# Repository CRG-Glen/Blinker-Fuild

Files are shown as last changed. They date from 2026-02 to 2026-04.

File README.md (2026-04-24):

# BLINKER FLUID

A completely pointless project.  

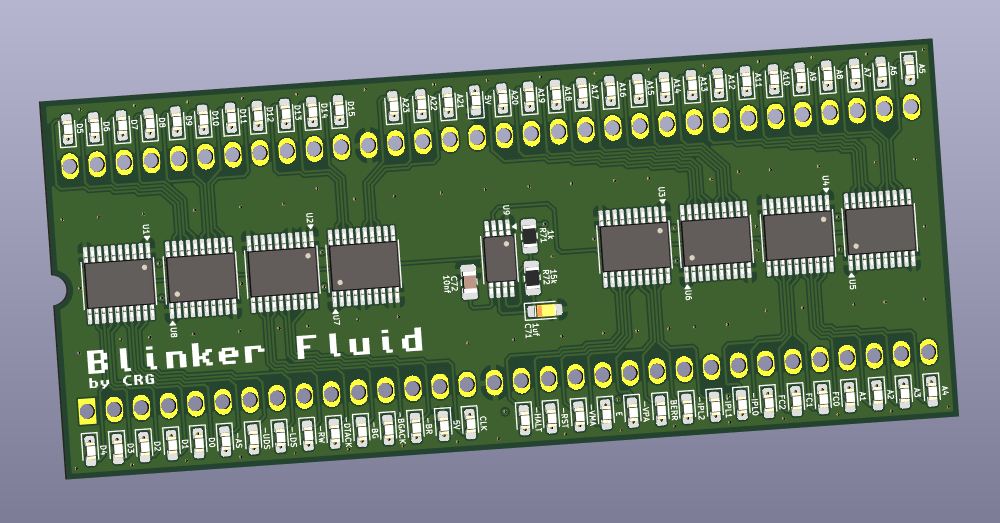
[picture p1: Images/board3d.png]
PCB


## What's this?  

Intended to sit inline with your 68000 CPU with LEDs on each signal that will light when that signal becomes active. 

It's just for fun and should not to be used for any diagnostic purposes, this isn't a logic probe!

There are 8nr 74HCT574s which are sampling each pin on the rising edge of a clock generated by a 555 timer.  
The 555 is running at a rate of approximately 50hz so will miss a lot of activity on the 68k.  There just
isn't enough room to do this with any accuracy but remember this is for fun only.  

You can adjust R71 and R72 to change the speed of the 555. 

## Assembly

Within the JLCPCB folder you will find Gerbers along with a BOM and CPL files suited to LCSC components.

The board can be produced with the HASL finish, no need to pay for EINT on this one but its mostly 0603 so 
get JLC (or equal) to do all SMD work.

Please note the BOM as included takes for RED LEDs for everything.  Feel free to change colours but remember 
you also need to adjust the resistor directly below each LED on the bottom side to suit your LEDs!

To keep the board tidy, there are no LED or Resistor designations on the PCB.  Just remember its all LEDs 
on the top side and all RESISTORs on the bottom side.  

## Bill of Materials

| Designation | Value | Type |
| --- | --- | --- |
| U1 - U8 | 74HCT574 | TSSOP20 |
| U9 | NE555 | TSSOP8 |
| LEDs | pick a colour | 0603 |
| Resistors | to suit your LED | 0603 |
| R71 | 1k ohm 1% | 0805 |
| R72 | 15kohm 1% | 0805 |
| C71 | 1uF | 0805 Tantalum |
| C72 | 10nF |0805 ceramic |
| C1-C8 + C73 | 0.1uF | 0603 ceramic |
| PINS | 0.5mm x 2.54mm x 9.7mm | individual machine pins |

## License

CERN Open Hardware Licence v2

Do with as you like just don't blame me if your computer, console or whatever else you install this in
goes up in smoke!

## Credits

PCB by CRG(Glen)

Artwork by Brick Studios

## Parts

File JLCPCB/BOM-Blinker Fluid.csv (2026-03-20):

Comment | Designator | Footprint | LCSC | Quantity
0.1uf | C1,C2,C3,C4,C5,C6,C7,C73,C8 | C_0603_1608Metric_Pad1.08x0.95mm_HandSolder | C14663 | 9
10nf | C72 | C_0805_2012Metric_Pad1.18x1.45mm_HandSolder | C1710 | 1
15k | R72 | R_0805_2012Metric_Pad1.20x1.40mm_HandSolder | C17475 | 1
1k | R71 | R_0805_2012Metric_Pad1.20x1.40mm_HandSolder | C17513 | 1
1uf | C71 | CP_EIA-2012-12_Kemet-R_Pad1.30x1.05mm_HandSolder | C7174 | 1
470 | R1,R10,R11,R12,R13,R14,R15,R17,R18,R19,R2,R20,R21,R22,R23,R24,R25,R26,R27,R28,R29,R3,R30,R31,R32,R33,R34,R35,R36,R37,R38,R39,R4,R40,R41,R42,R43,R44,R45,R46,R47,R48,R49,R5,R50,R51,R52,R53,R54,R55,R56,R57,R58,R59,R6,R60,R61,R62,R63,R7,R8,R9 | R_0603_1608Metric_Pad0.98x0.95mm_HandSolder | C23179 | 62
74HCT574 | U1,U2,U3,U4,U5,U6,U7,U8 | TSSOP-20_4.4x6.5mm_P0.65mm | C2677898 | 8
NE555 | U9 | TSSOP-8_4.4x3mm_P0.65mm | C105643 | 1
RED | D1,D10,D11,D12,D13,D14,D15,D17,D18,D19,D2,D20,D21,D22,D23,D24,D25,D26,D27,D28,D29,D3,D30,D31,D32,D33,D34,D35,D36,D37,D38,D39,D4,D40,D41,D42,D43,D44,D45,D46,D47,D48,D49,D5,D50,D51,D52,D53,D54,D55,D56,D57,D58,D59,D6,D60,D61,D62,D63,D7,D8,D9 | LED_0603_1608Metric_Pad1.05x0.95mm_HandSolder | C2286 | 62
Conn_02x32_Counter_Clockwise | J1 | DIP-64_W22.86mm_LongPads |  | 1

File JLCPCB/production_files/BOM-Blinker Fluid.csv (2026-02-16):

Comment | Designator | Footprint | LCSC | Quantity
0.1uf | C1,C2,C3,C4,C5,C6,C7,C73,C8 | C_0402_1005Metric_Pad0.74x0.62mm_HandSolder | C141382 | 9
10nf | C72 | C_0402_1005Metric_Pad0.74x0.62mm_HandSolder | C15195 | 1
1k | R71 | R_0402_1005Metric_Pad0.72x0.64mm_HandSolder | C11702 | 1
1uf | C71 | CP_EIA-2012-12_Kemet-R_Pad1.30x1.05mm_HandSolder | C1953183 | 1
330 | R1,R2,R3,R4,R5,R53,R54,R55,R56,R57,R58,R59,R60,R61,R62,R63 | R_0402_1005Metric_Pad0.72x0.64mm_HandSolder | C25104 | 16
470 | R28,R29,R30,R31,R32,R33,R34,R35,R36,R37,R38,R39,R40,R41,R42,R43,R44,R45,R46,R47,R48,R50,R51,R52 | R_0402_1005Metric_Pad0.72x0.64mm_HandSolder | C25117 | 24
47k | R72 | R_0402_1005Metric_Pad0.72x0.64mm_HandSolder | C25792 | 1
680 | R10,R11,R12,R13,R14,R15,R17,R18,R19,R20,R21,R22,R23,R24,R25,R26,R27,R49,R6,R7,R8,R9 | R_0402_1005Metric_Pad0.72x0.64mm_HandSolder | C25130 | 22
74HCT574 | U1,U2,U3,U4,U5,U6,U7,U8 | TSSOP-20_4.4x6.5mm_P0.65mm | C2677898 | 8
BLUE | D10,D11,D12,D13,D15,D17,D18,D19,D20,D21,D22,D23,D24,D25,D26,D27,D28,D6,D7,D8,D9 | LED_0402_1005Metric_Pad0.77x0.64mm_HandSolder | C131223 | 21
Conn_02x32_Counter_Clockwise | J1 | DIP-64_W22.86mm_LongPads | C130723 | 1
GREEN | D29,D30,D31,D32,D33,D34,D35,D36,D37,D38,D39,D40,D41,D42,D43,D44,D45,D46,D47,D48,D50,D51,D52 | LED_0402_1005Metric_Pad0.77x0.64mm_HandSolder | C74338 | 23
NE555 | U9 | TSSOP-8_4.4x3mm_P0.65mm | C105643 | 1
RED | D1,D2,D3,D4,D5,D53,D54,D55,D56,D57,D58,D59,D60,D61,D62,D63 | LED_0402_1005Metric_Pad0.77x0.64mm_HandSolder | C71911 | 16
WHITE | D14,D49 | LED_0402_1005Metric_Pad0.77x0.64mm_HandSolder | C74340 | 2

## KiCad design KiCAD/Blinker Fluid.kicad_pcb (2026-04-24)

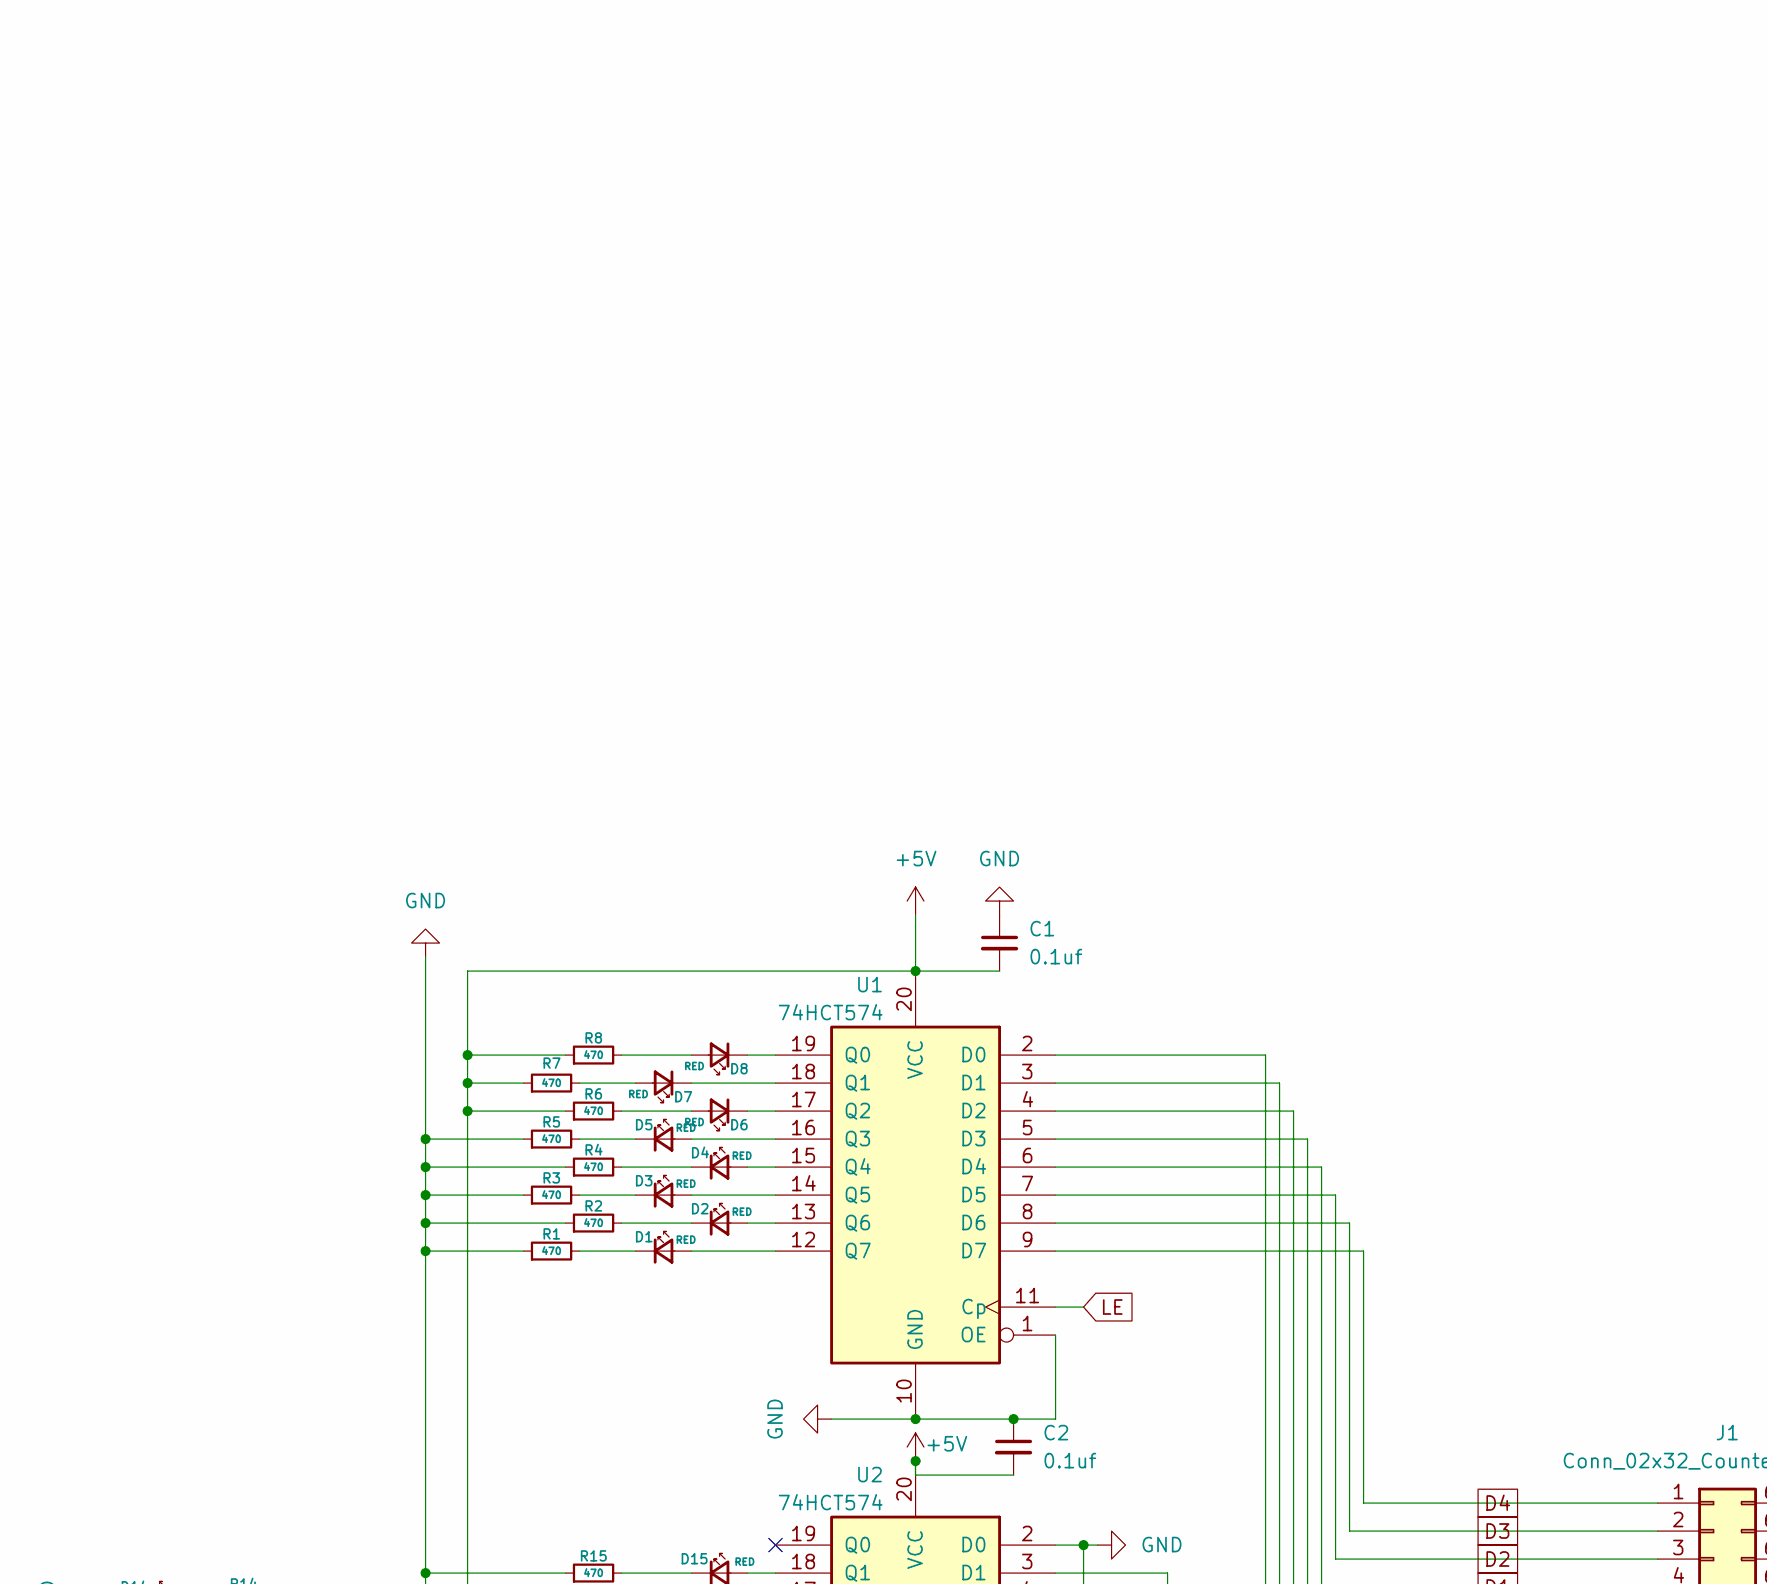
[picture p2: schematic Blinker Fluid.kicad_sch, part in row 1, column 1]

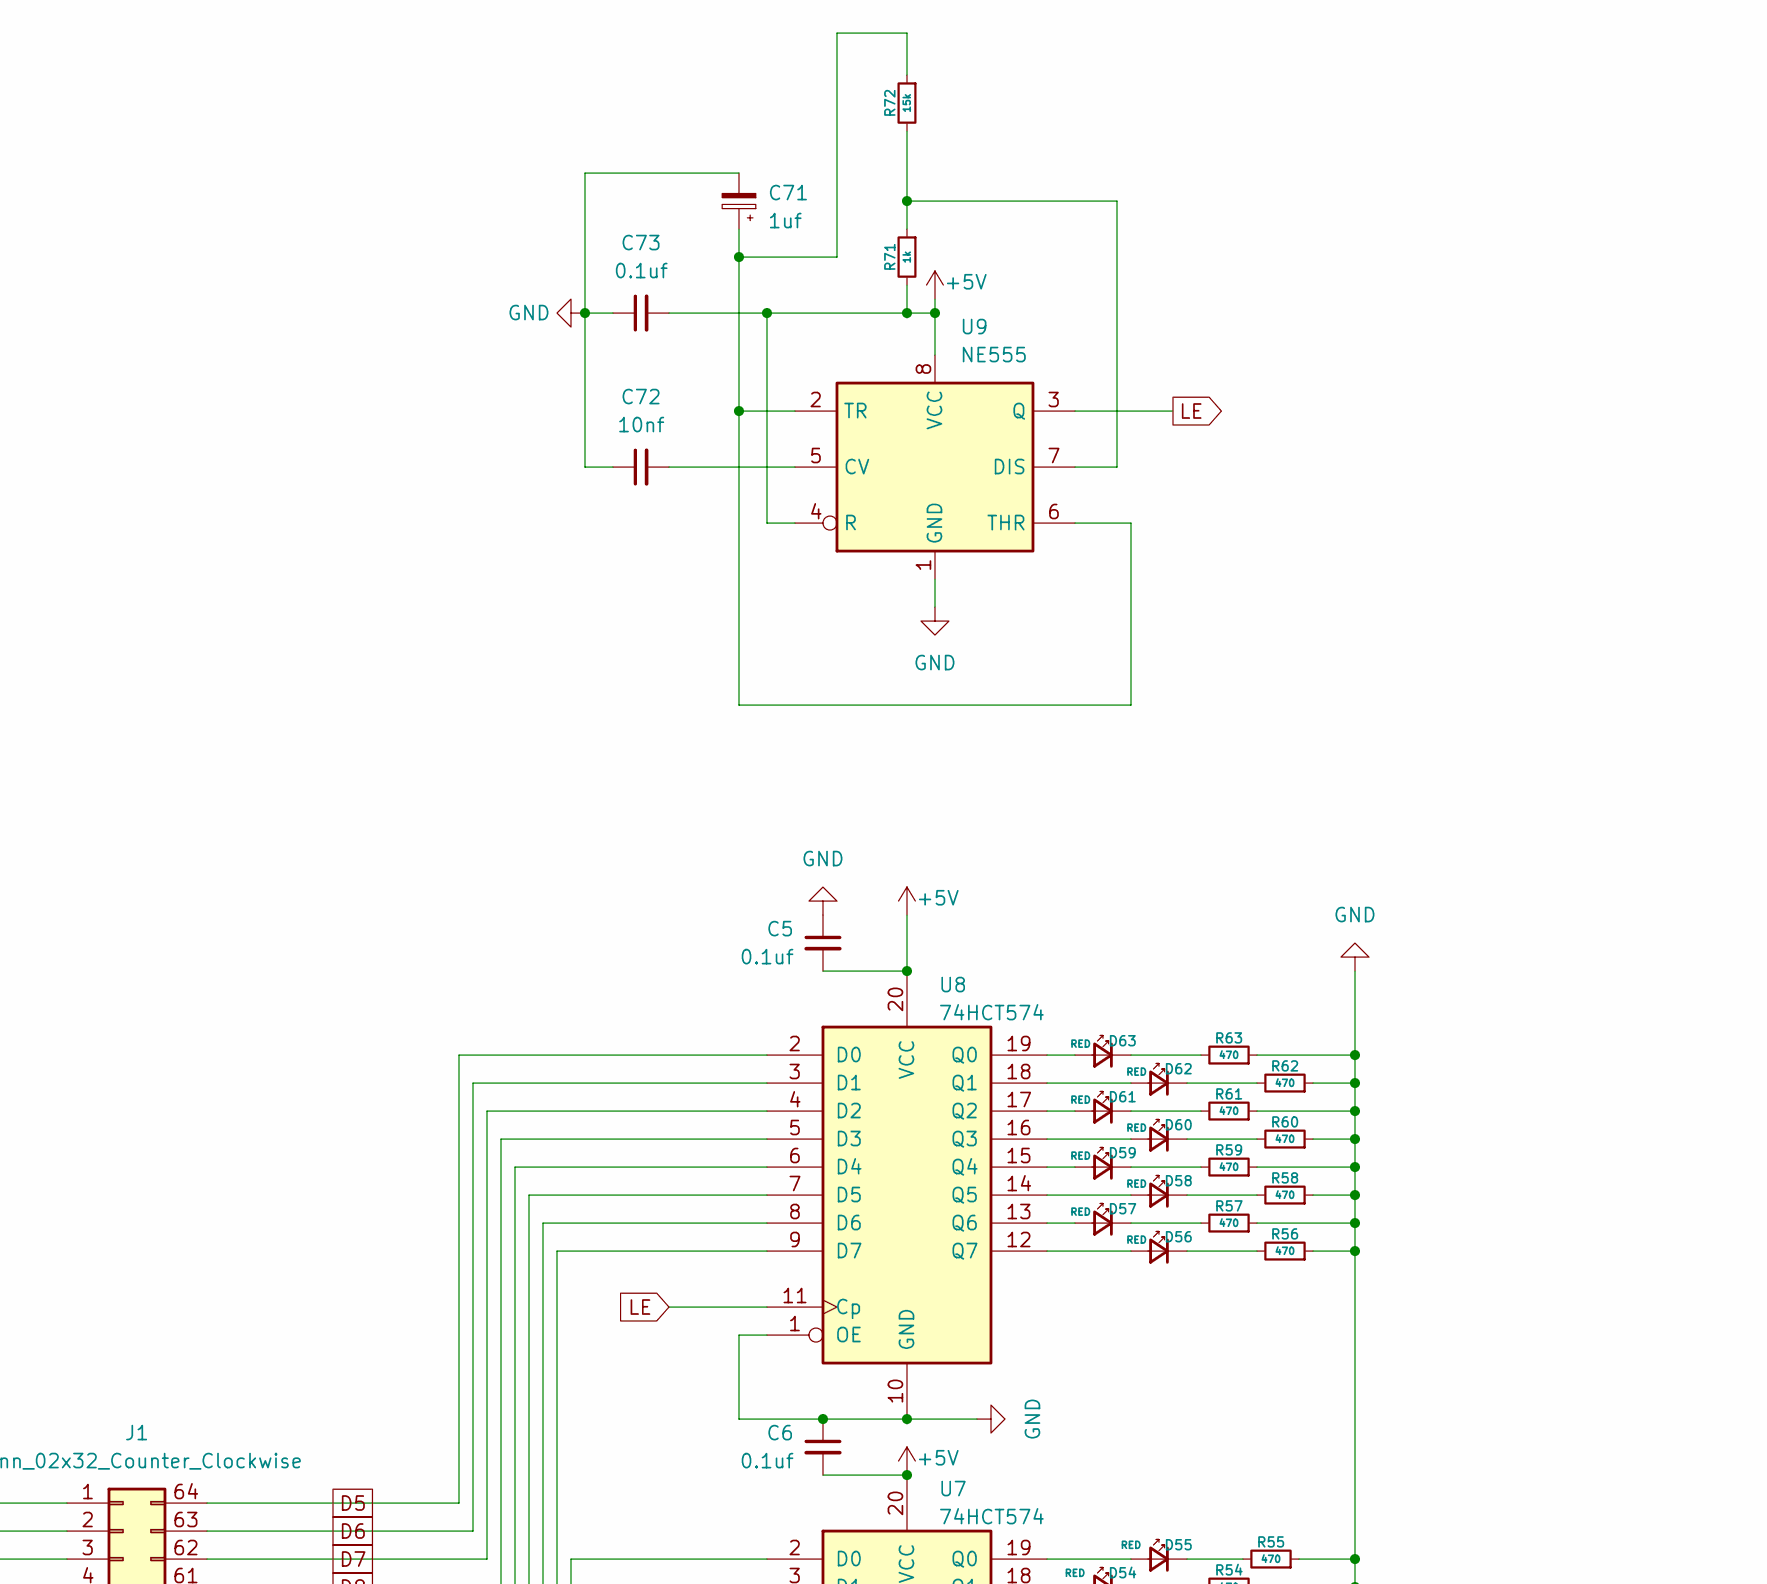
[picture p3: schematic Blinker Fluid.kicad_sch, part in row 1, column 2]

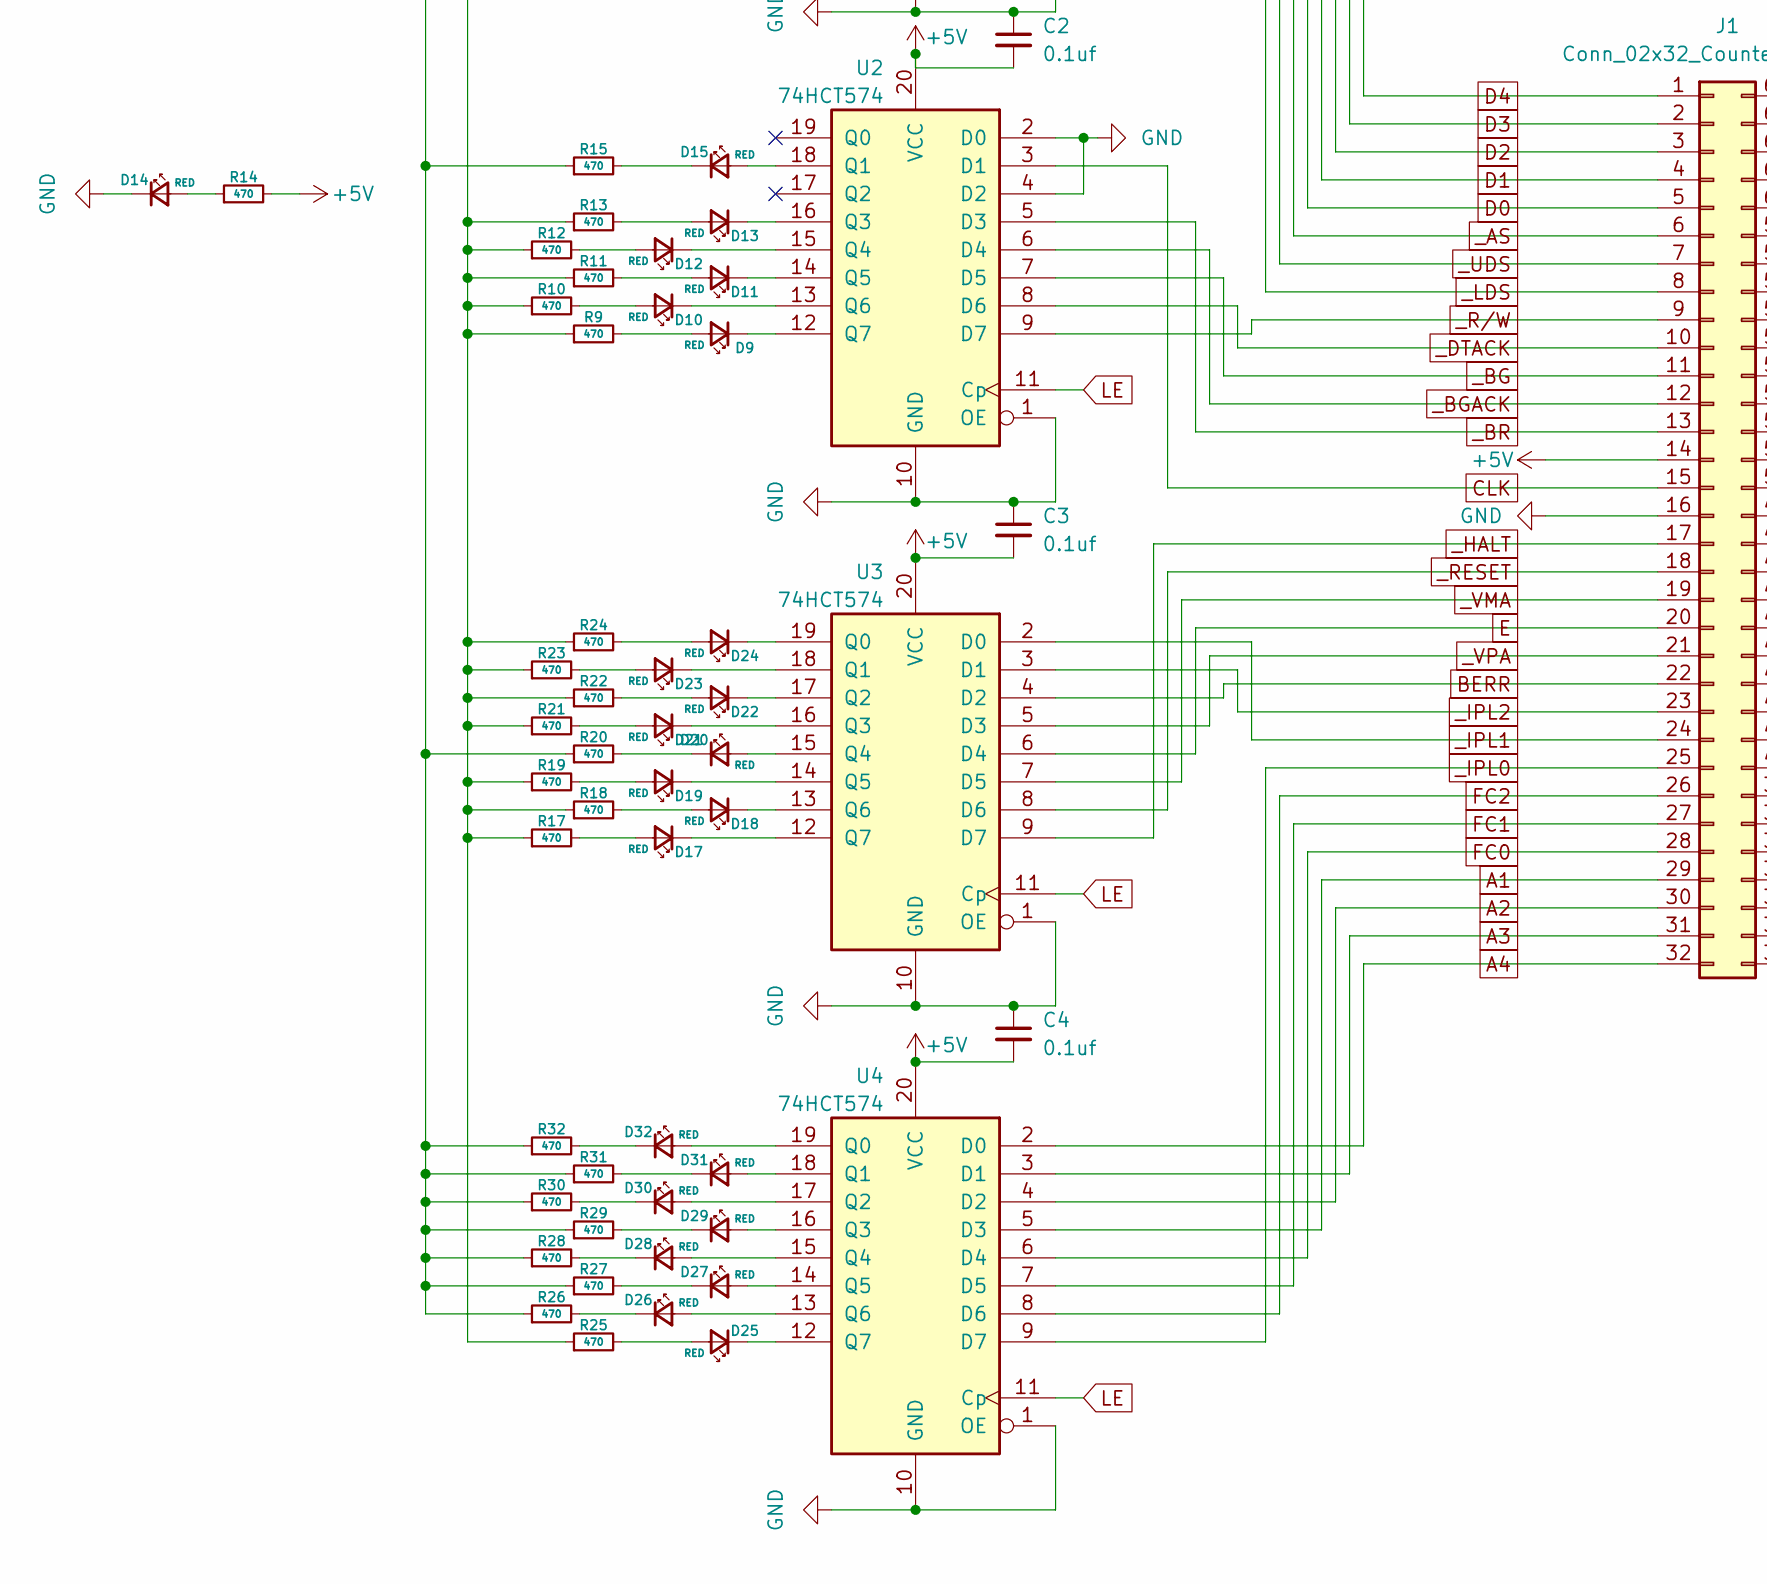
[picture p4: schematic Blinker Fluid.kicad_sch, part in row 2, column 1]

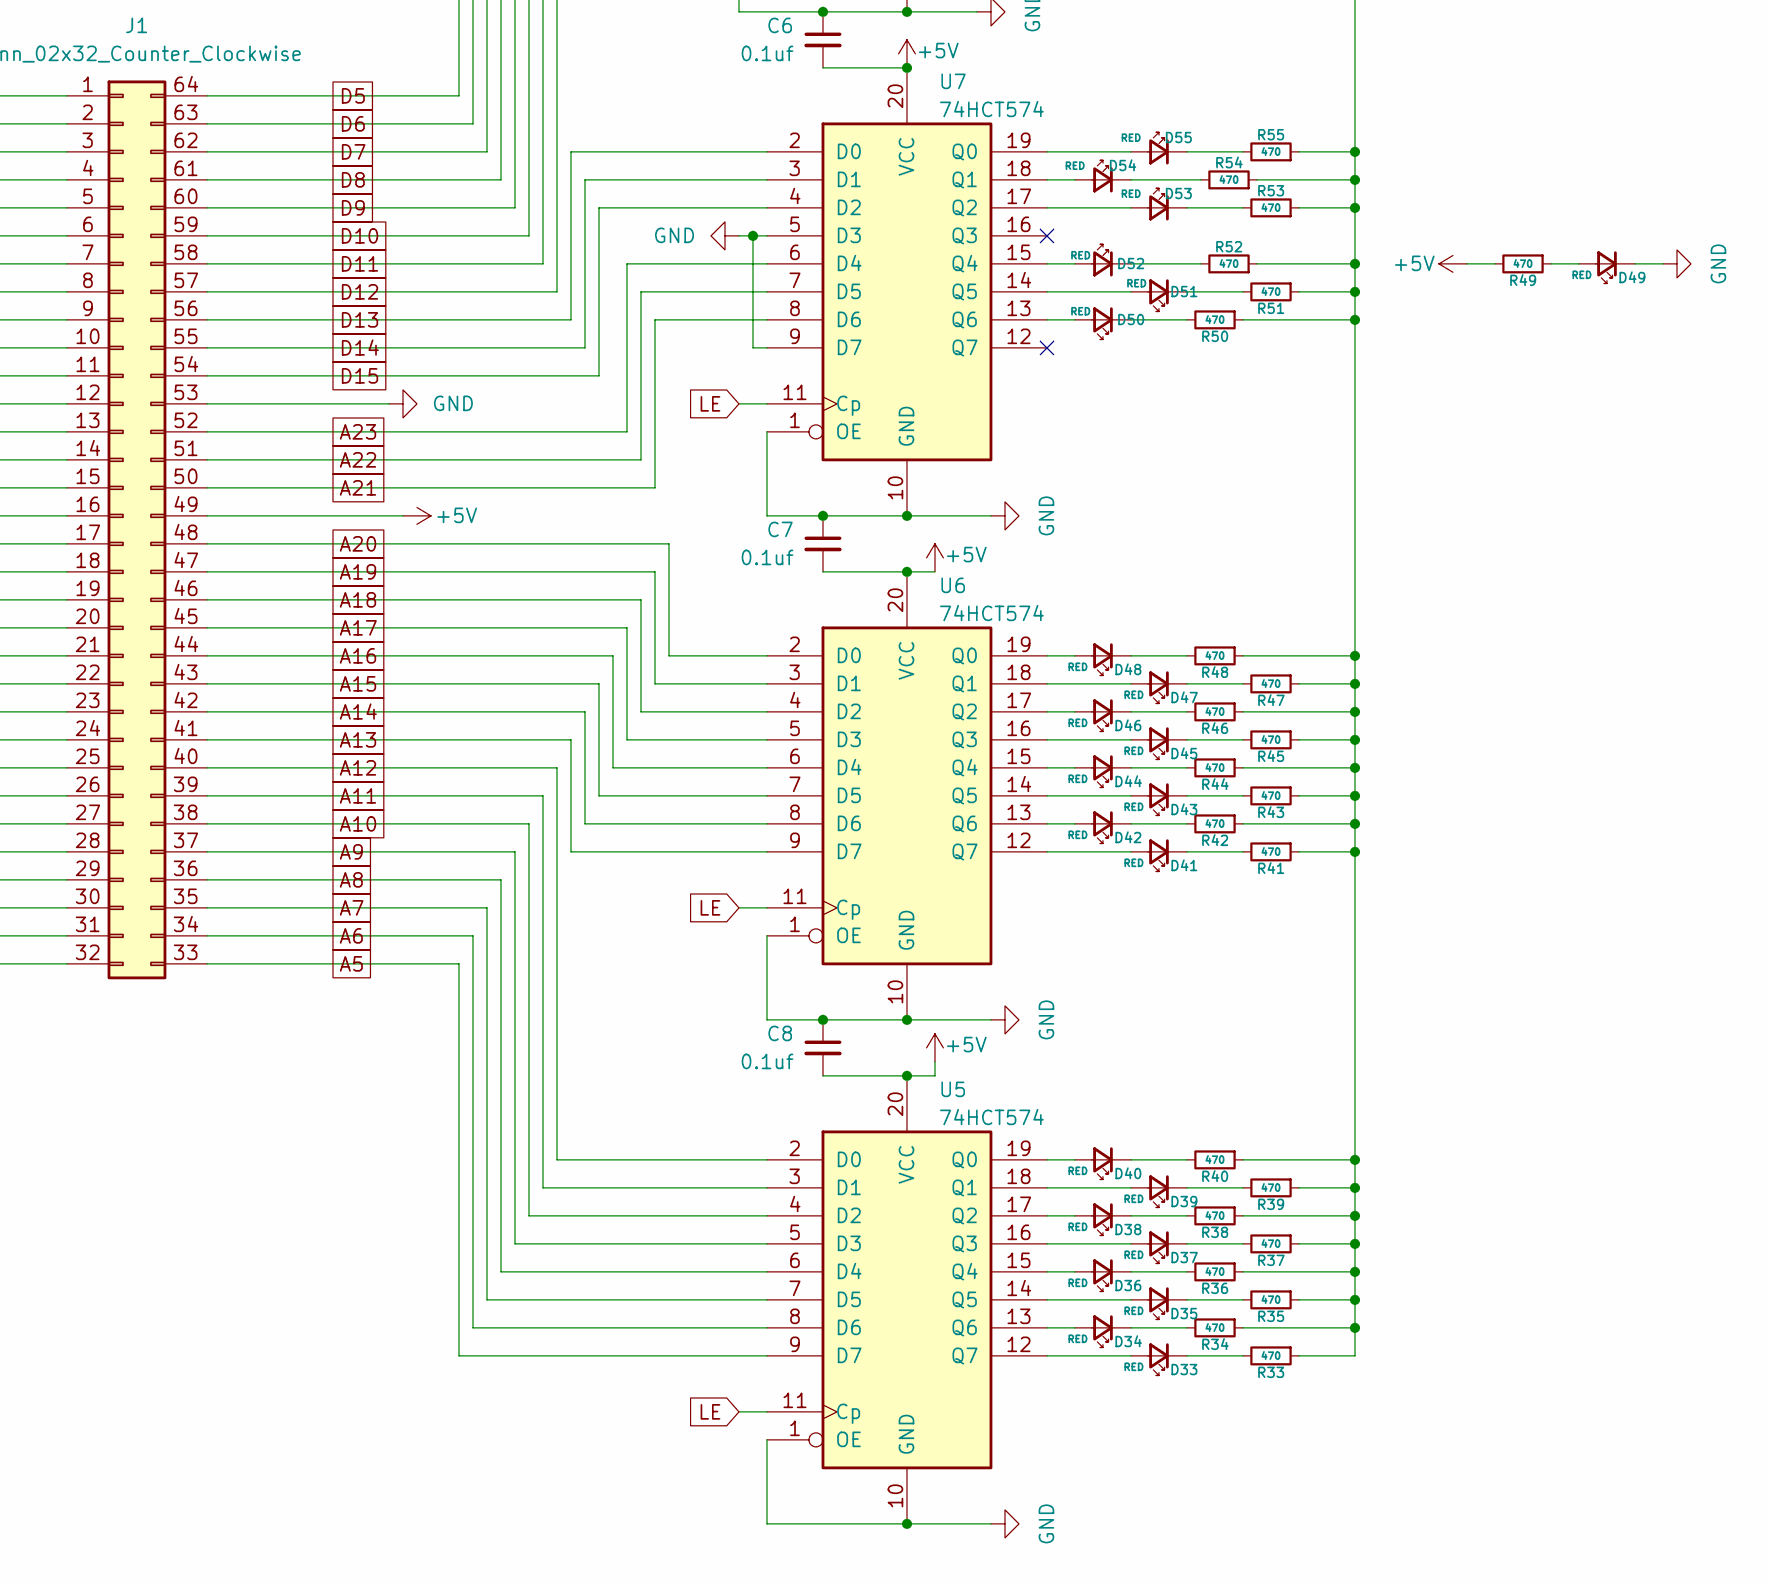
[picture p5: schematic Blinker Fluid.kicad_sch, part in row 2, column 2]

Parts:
C1, C2, C3, C4, C5, C6, C7, C8, C73: 0.1uf; C_0603_1608Metric_Pad1.08x0.95mm_HandSolder; LCSC C14663
C71: 1uf; CP_EIA-2012-12_Kemet-R_Pad1.30x1.05mm_HandSolder; LCSC C7174
C72: 10nf; C_0805_2012Metric_Pad1.18x1.45mm_HandSolder; LCSC C15195
D1, D2, D3, D4, D5, D6, D7, D8, D9, D10, D11, D12, D13, D14, D15, D17, D18, D19, D20, D21, D22, D23, D24, D25, D26, D27, D28, D29, D30, D31, D32, D33, D34, D35, D36, D37, D38, D39, D40, D41, D42, D43, D44, D45, D46, D47, D48, D49, D50, D51, D52, D53, D54, D55, D56, D57, D58, D59, D60, D61, D62, D63: RED; LED_0603_1608Metric_Pad1.05x0.95mm_HandSolder; LCSC C2286
J1: Conn_02x32_Counter_Clockwise; DIP-64_W22.86mm_LongPads; LCSC C130723
R1, R2, R3, R4, R5, R6, R7, R8, R9, R10, R11, R12, R13, R14, R15, R17, R18, R19, R20, R21, R22, R23, R24, R25, R26, R27, R28, R29, R30, R31, R32, R33, R34, R35, R36, R37, R38, R39, R40, R41, R42, R43, R44, R45, R46, R47, R48, R49, R50, R51, R52, R53, R54, R55, R56, R57, R58, R59, R60, R61, R62, R63: 470; R_0603_1608Metric_Pad0.98x0.95mm_HandSolder; LCSC C23179
R71: 1k; R_0805_2012Metric_Pad1.20x1.40mm_HandSolder; LCSC C17513
R72: 15k; R_0805_2012Metric_Pad1.20x1.40mm_HandSolder; LCSC C17475
U1, U2, U3, U4, U5, U6, U7, U8: 74HCT574; TSSOP-20_4.4x6.5mm_P0.65mm; LCSC C2677898
U9: NE555; TSSOP-8_4.4x3mm_P0.65mm; LCSC C105643

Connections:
+5V: C1.2, C2.2, C3.2, C4.2, C5.2, C6.2, C7.2, C8.2, C73.2, J1.14, J1.49, R6.1, R7.1, R8.1, R9.1, R10.1, R11.1, R12.1, R13.1, R14.2, R17.1, R18.1, R19.1, R21.1, R22.1, R23.1, R24.1, R25.1, R49.2, R71.2, U1.20 (VCC), U2.20 (VCC), U3.20 (VCC), U4.20 (VCC), U5.20 (VCC), U6.20 (VCC), U7.20 (VCC), U8.20 (VCC), U9.4 (R), U9.8 (VCC)
A1: J1.29, U4.5 (D3)
A2: J1.30, U4.4 (D2)
A3: J1.31, U4.3 (D1)
A4: J1.32, U4.2 (D0)
A5: J1.33, U5.9 (D7)
A6: J1.34, U5.8 (D6)
A7: J1.35, U5.7 (D5)
A8: J1.36, U5.6 (D4)
A9: J1.37, U5.5 (D3)
A10: J1.38, U5.4 (D2)
A11: J1.39, U5.3 (D1)
A12: J1.40, U5.2 (D0)
A13: J1.41, U6.9 (D7)
A14: J1.42, U6.8 (D6)
A15: J1.43, U6.7 (D5)
A16: J1.44, U6.6 (D4)
A17: J1.45, U6.5 (D3)
A18: J1.46, U6.4 (D2)
A19: J1.47, U6.3 (D1)
A20: J1.48, U6.2 (D0)
A21: J1.50, U7.8 (D6)
A22: J1.51, U7.7 (D5)
A23: J1.52, U7.6 (D4)
BERR: J1.22, U3.4 (D2)
CLK: J1.15, U2.3 (D1)
D0: J1.5, U1.5 (D3)
D1: J1.4, U1.6 (D4)
D2: J1.3, U1.7 (D5)
D3: J1.2, U1.8 (D6)
D4: J1.1, U1.9 (D7)
D5: J1.64, U8.2 (D0)
D6: J1.63, U8.3 (D1)
D7: J1.62, U8.4 (D2)
D8: J1.61, U8.5 (D3)
D9: J1.60, U8.6 (D4)
D10: J1.59, U8.7 (D5)
D11: J1.58, U8.8 (D6)
D12: J1.57, U8.9 (D7)
D13: J1.56, U7.2 (D0)
D14: J1.55, U7.3 (D1)
D15: J1.54, U7.4 (D2)
E: J1.20, U3.6 (D4)
FC0: J1.28, U4.6 (D4)
FC1: J1.27, U4.7 (D5)
FC2: J1.26, U4.8 (D6)
GND: C1.1, C2.1, C3.1, C4.1, C5.1, C6.1, C7.1, C8.1, C71.2, C72.1, C73.1, D14.1 (K), D49.1 (K), J1.16, J1.53, R1.1, R2.1, R3.1, R4.1, R5.1, R15.1, R20.1, R26.1, R27.1, R28.1, R29.1, R30.1, R31.1, R32.1, R33.1, R34.1, R35.1, R36.1, R37.1, R38.1, R39.1, R40.1, R41.1, R42.1, R43.1, R44.1, R45.1, R46.1, R47.1, R48.1, R50.1, R51.1, R52.1, R53.1, R54.1, R55.1, R56.1, R57.1, R58.1, R59.1, R60.1, R61.1, R62.1, R63.1, U1.1 (OE), U1.10 (GND), U2.1 (OE), U2.2 (D0), U2.4 (D2), U2.10 (GND), U3.1 (OE), U3.10 (GND), U4.1 (OE), U4.10 (GND), U5.1 (OE), U5.10 (GND), U6.1 (OE), U6.10 (GND), U7.1 (OE), U7.5 (D3), U7.9 (D7), U7.10 (GND), U8.1 (OE), U8.10 (GND), U9.1 (GND)
LE: U1.11 (Cp), U2.11 (Cp), U3.11 (Cp), U4.11 (Cp), U5.11 (Cp), U6.11 (Cp), U7.11 (Cp), U8.11 (Cp), U9.3 (Q)
unnamed: D1.2 (A), U1.12 (Q7)
unnamed: D1.1 (K), R1.2
unnamed: D2.2 (A), U1.13 (Q6)
unnamed: D2.1 (K), R2.2
unnamed: D3.2 (A), U1.14 (Q5)
unnamed: D3.1 (K), R3.2
unnamed: D4.2 (A), U1.15 (Q4)
unnamed: D4.1 (K), R4.2
unnamed: D5.2 (A), U1.16 (Q3)
unnamed: D5.1 (K), R5.2
unnamed: D6.2 (A), R6.2
unnamed: D6.1 (K), U1.17 (Q2)
unnamed: D7.2 (A), R7.2
unnamed: D7.1 (K), U1.18 (Q1)
unnamed: D8.2 (A), R8.2
unnamed: D8.1 (K), U1.19 (Q0)
unnamed: D9.2 (A), R9.2
unnamed: D9.1 (K), U2.12 (Q7)
unnamed: D10.2 (A), R10.2
unnamed: D10.1 (K), U2.13 (Q6)
unnamed: D11.2 (A), R11.2
unnamed: D11.1 (K), U2.14 (Q5)
unnamed: D12.2 (A), R12.2
unnamed: D12.1 (K), U2.15 (Q4)
unnamed: D13.2 (A), R13.2
unnamed: D13.1 (K), U2.16 (Q3)
unnamed: D14.2 (A), R14.1
unnamed: D15.2 (A), U2.18 (Q1)
unnamed: D15.1 (K), R15.2
unnamed: D17.2 (A), R17.2
unnamed: D17.1 (K), U3.12 (Q7)
unnamed: D18.2 (A), R18.2
unnamed: D18.1 (K), U3.13 (Q6)
unnamed: D19.2 (A), R19.2
unnamed: D19.1 (K), U3.14 (Q5)
unnamed: D20.2 (A), U3.15 (Q4)
unnamed: D20.1 (K), R20.2
unnamed: D21.2 (A), R21.2
unnamed: D21.1 (K), U3.16 (Q3)
unnamed: D22.2 (A), R22.2
unnamed: D22.1 (K), U3.17 (Q2)
unnamed: D23.2 (A), R23.2
unnamed: D23.1 (K), U3.18 (Q1)
unnamed: D24.2 (A), R24.2
unnamed: D24.1 (K), U3.19 (Q0)
unnamed: D25.2 (A), R25.2
unnamed: D25.1 (K), U4.12 (Q7)
unnamed: D26.2 (A), U4.13 (Q6)
unnamed: D26.1 (K), R26.2
unnamed: D27.2 (A), U4.14 (Q5)
unnamed: D27.1 (K), R27.2
unnamed: D28.2 (A), U4.15 (Q4)
unnamed: D28.1 (K), R28.2
unnamed: D29.2 (A), U4.16 (Q3)
unnamed: D29.1 (K), R29.2
unnamed: D30.2 (A), U4.17 (Q2)
unnamed: D30.1 (K), R30.2
unnamed: D31.2 (A), U4.18 (Q1)
unnamed: D31.1 (K), R31.2
unnamed: D32.2 (A), U4.19 (Q0)
unnamed: D32.1 (K), R32.2
unnamed: D33.2 (A), U5.12 (Q7)
unnamed: D33.1 (K), R33.2
unnamed: D34.2 (A), U5.13 (Q6)
unnamed: D34.1 (K), R34.2
unnamed: D35.2 (A), U5.14 (Q5)
unnamed: D35.1 (K), R35.2
unnamed: D36.2 (A), U5.15 (Q4)
unnamed: D36.1 (K), R36.2
unnamed: D37.2 (A), U5.16 (Q3)
unnamed: D37.1 (K), R37.2
unnamed: D38.2 (A), U5.17 (Q2)
unnamed: D38.1 (K), R38.2
unnamed: D39.2 (A), U5.18 (Q1)
unnamed: D39.1 (K), R39.2
unnamed: D40.2 (A), U5.19 (Q0)
unnamed: D40.1 (K), R40.2
unnamed: D41.2 (A), U6.12 (Q7)
unnamed: D41.1 (K), R41.2
unnamed: D42.2 (A), U6.13 (Q6)
unnamed: D42.1 (K), R42.2
unnamed: D43.2 (A), U6.14 (Q5)
unnamed: D43.1 (K), R43.2
unnamed: D44.2 (A), U6.15 (Q4)
unnamed: D44.1 (K), R44.2
unnamed: D45.2 (A), U6.16 (Q3)
unnamed: D45.1 (K), R45.2
unnamed: D46.2 (A), U6.17 (Q2)
unnamed: D46.1 (K), R46.2
unnamed: D47.2 (A), U6.18 (Q1)
unnamed: D47.1 (K), R47.2
unnamed: D48.2 (A), U6.19 (Q0)
unnamed: D48.1 (K), R48.2
unnamed: D49.2 (A), R49.1
unnamed: D50.2 (A), U7.13 (Q6)
unnamed: D50.1 (K), R50.2
unnamed: D51.2 (A), U7.14 (Q5)
unnamed: D51.1 (K), R51.2
unnamed: D52.2 (A), U7.15 (Q4)
unnamed: D52.1 (K), R52.2
unnamed: D53.2 (A), U7.17 (Q2)
unnamed: D53.1 (K), R53.2
unnamed: D54.2 (A), U7.18 (Q1)
unnamed: D54.1 (K), R54.2
unnamed: D55.2 (A), U7.19 (Q0)
unnamed: D55.1 (K), R55.2
unnamed: D56.2 (A), U8.12 (Q7)
unnamed: D56.1 (K), R56.2
unnamed: D57.2 (A), U8.13 (Q6)
unnamed: D57.1 (K), R57.2
unnamed: D58.2 (A), U8.14 (Q5)
unnamed: D58.1 (K), R58.2
unnamed: D59.2 (A), U8.15 (Q4)
unnamed: D59.1 (K), R59.2
unnamed: D60.2 (A), U8.16 (Q3)
unnamed: D60.1 (K), R60.2
unnamed: D61.2 (A), U8.17 (Q2)
unnamed: D61.1 (K), R61.2
unnamed: D62.2 (A), U8.18 (Q1)
unnamed: D62.1 (K), R62.2
unnamed: D63.2 (A), U8.19 (Q0)
unnamed: D63.1 (K), R63.2
unnamed: C72.2, U9.5 (CV)
unnamed: R71.1, R72.2, U9.7 (DIS)
unnamed: C71.1, R72.1, U9.2 (TR), U9.6 (THR)
_AS: J1.6, U1.4 (D2)
_BG: J1.11, U2.7 (D5)
_BGACK: J1.12, U2.6 (D4)
_BR: J1.13, U2.5 (D3)
_DTACK: J1.10, U2.8 (D6)
_HALT: J1.17, U3.9 (D7)
_IPL0: J1.25, U4.9 (D7)
_IPL1: J1.24, U3.2 (D0)
_IPL2: J1.23, U3.3 (D1)
_LDS: J1.8, U1.2 (D0)
_RESET: J1.18, U3.8 (D6)
_R/W: J1.9, U2.9 (D7)
_UDS: J1.7, U1.3 (D1)
_VMA: J1.19, U3.7 (D5)
_VPA: J1.21, U3.5 (D3)

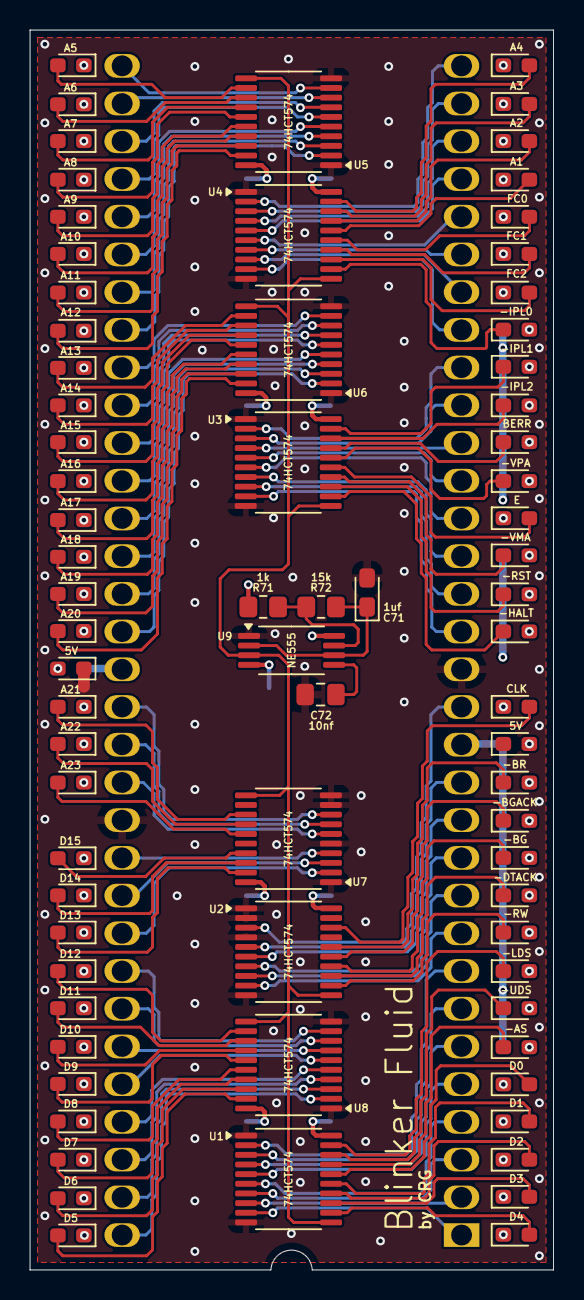
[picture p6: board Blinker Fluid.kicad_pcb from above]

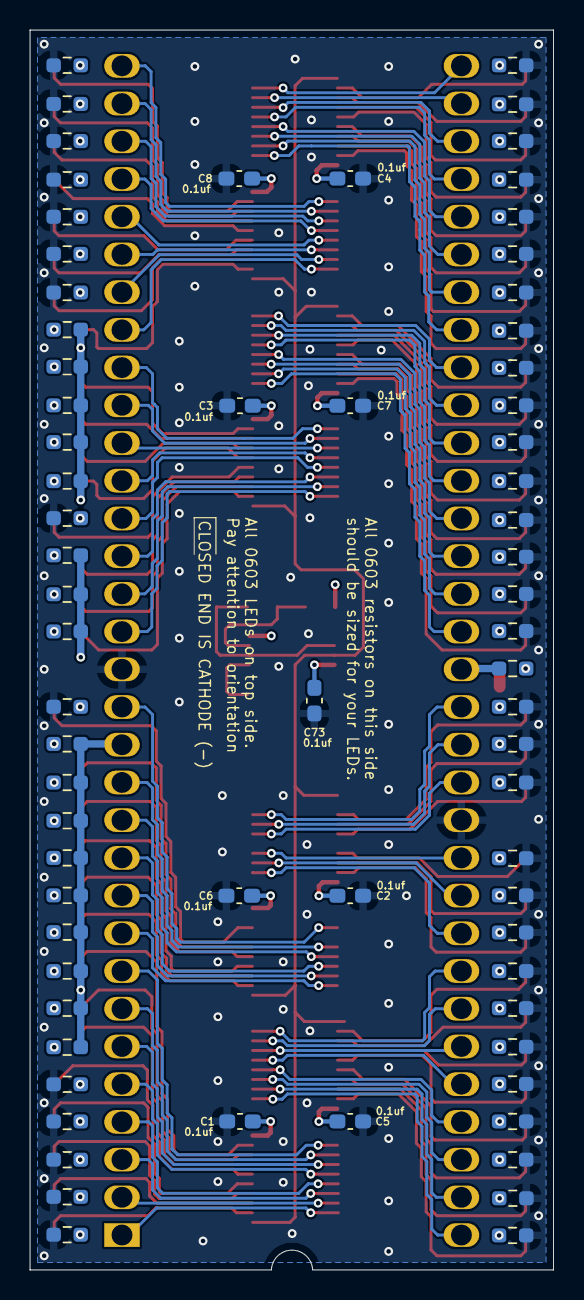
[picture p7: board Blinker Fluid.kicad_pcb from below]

Board: 4 copper layers, 35.2 x 83.5 mm, 147 parts (71 on the bottom side), 188 nets.

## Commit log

2026-02-17 Updated 17-02-26
    [BOM-Blinker Fluid.csv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]
2026-02-25 Updated 25-02-26
    [BOM-Blinker Fluid.csv, Blinker Fluid.kicad_pcb, Blinker Fluid.kicad_sch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]
2026-03-20 Minor corrections
    [BOM-Blinker Fluid.csv, Blinker Fluid.kicad_pcb, Blinker Fluid.kicad_sch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]
2026-03-20 Update capacitor C72 description to '0805 ceramic'
2026-03-20 Update pin specifications in README
2026-04-24 PCB revised to clear short
    [Blinker Fluid.kicad_pcb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]
